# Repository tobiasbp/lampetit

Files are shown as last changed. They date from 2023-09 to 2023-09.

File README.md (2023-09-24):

# Lampetit Conversion
A project to convert the Lampetit lamp by Louis Poulsen to a portable LED lamp.

# Create the Gerber files

The following is the high level view of the process. Read the
[description from JLCPVB](https://jlcpcb.com/help/article/16-How-to-generate-Gerber-and-Drill-files-in-KiCad-6)
for all the details.

1. File -> Fabrication outputs -> Gerbers
2. Press _Plot_ to greate Gerbers
3. Press _Generate Drill Files..._

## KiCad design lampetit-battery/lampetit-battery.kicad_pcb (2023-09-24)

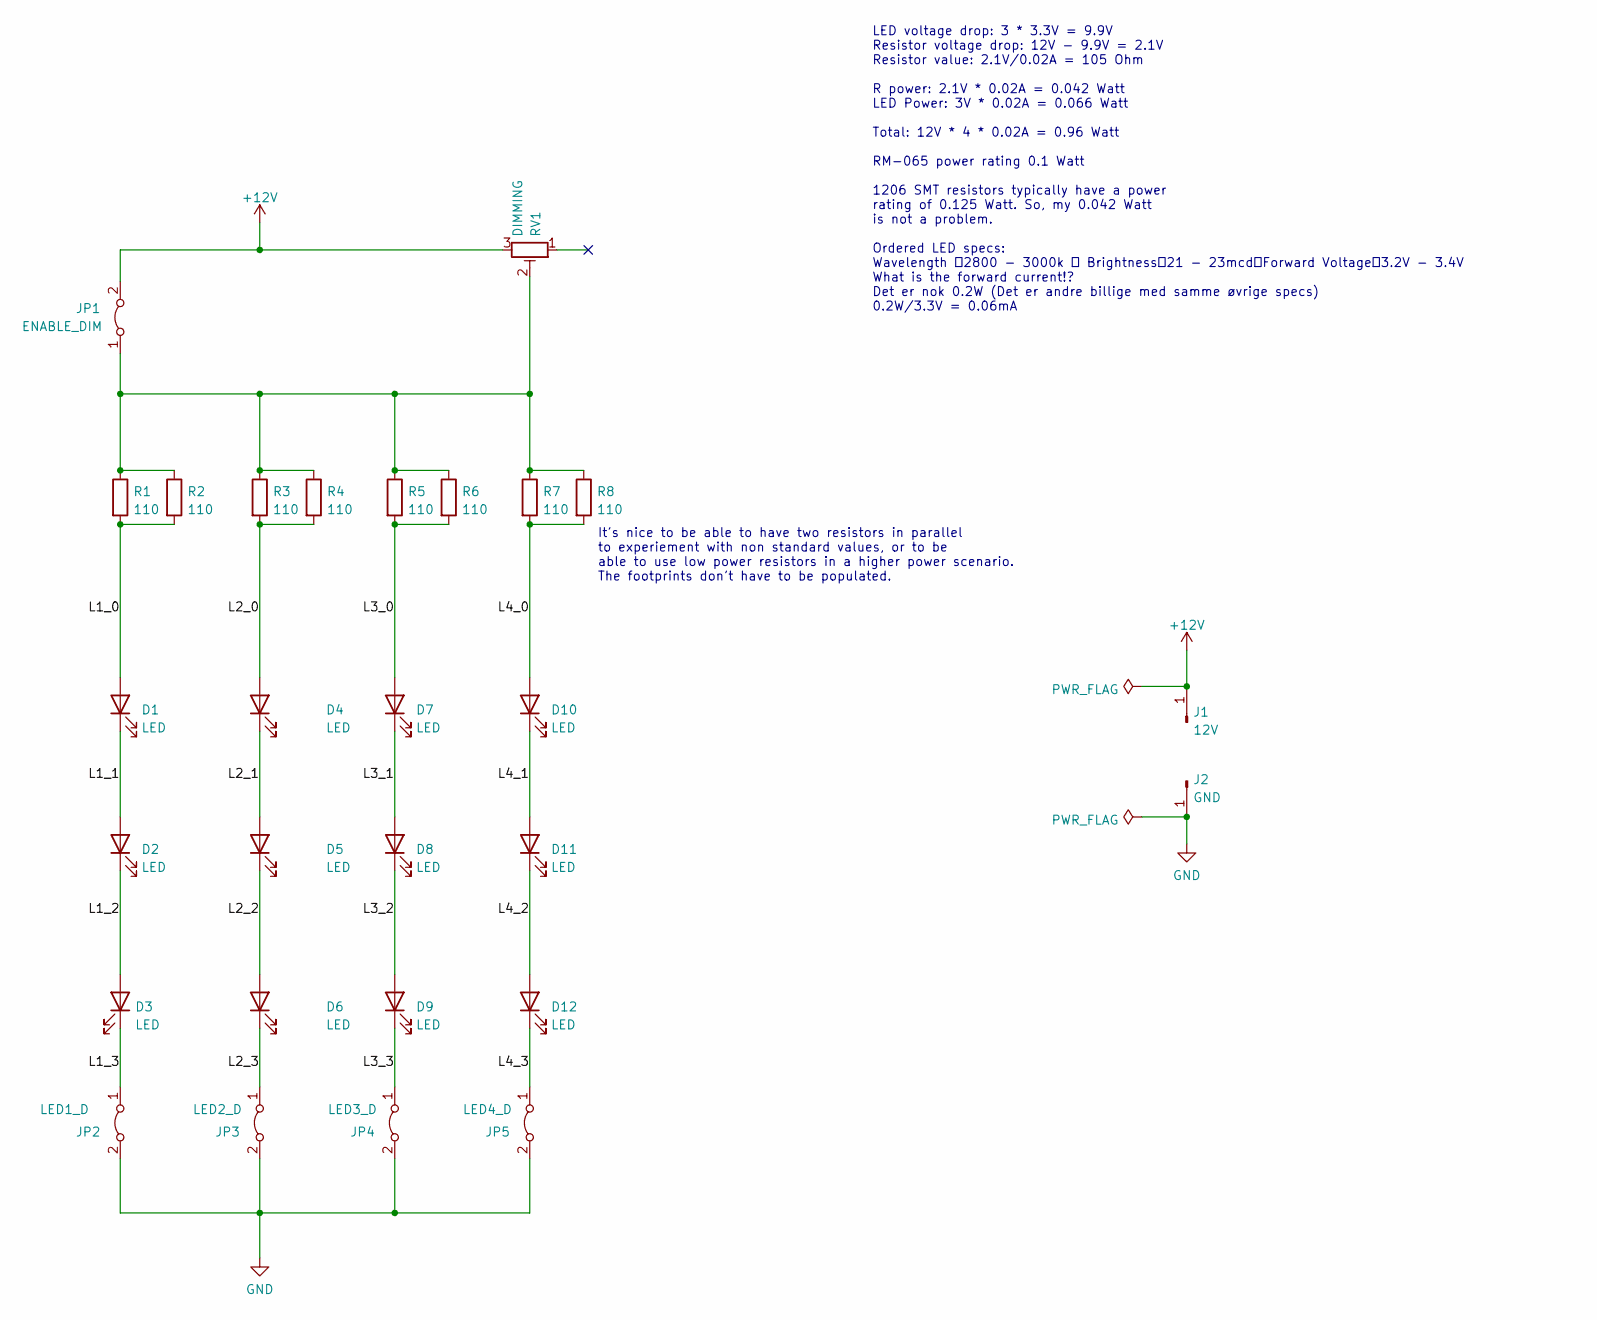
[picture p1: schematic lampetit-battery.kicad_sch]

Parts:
D1, D2, D3, D4, D5, D6, D7, D8, D9, D10, D11, D12: LED; LED_PLCC_2835_Handsoldering
J1: 12V; PinHeader_1x01_P2.54mm_Vertical
J2: GND; PinHeader_1x01_P2.54mm_Vertical
JP1: ENABLE_DIM; SolderJumper-2_P1.3mm_Bridged_Pad1.0x1.5mm
JP2: LED1_D; SolderJumper-2_P1.3mm_Bridged_Pad1.0x1.5mm
JP3: LED2_D; SolderJumper-2_P1.3mm_Bridged_Pad1.0x1.5mm
JP4: LED3_D; SolderJumper-2_P1.3mm_Bridged_Pad1.0x1.5mm
JP5: LED4_D; SolderJumper-2_P1.3mm_Bridged_Pad1.0x1.5mm
R1, R2, R3, R4, R5, R6, R7, R8: 110; R_1206_3216Metric_Pad1.30x1.75mm_HandSolder
RV1: DIMMING; Potentiometer_Runtron_RM-065_Vertical

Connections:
+12V: J1.1, JP1.2 (B), RV1.3
/L1_0: D1.2 (A), R1.2, R2.2
/L1_1: D1.1 (K), D2.2 (A)
/L1_2: D2.1 (K), D3.2 (A)
/L1_3: D3.1 (K), JP2.1 (A)
/L2_0: D4.2 (A), R3.2, R4.2
/L2_1: D4.1 (K), D5.2 (A)
/L2_2: D5.1 (K), D6.2 (A)
/L2_3: D6.1 (K), JP3.1 (A)
/L3_0: D7.2 (A), R5.2, R6.2
/L3_1: D7.1 (K), D8.2 (A)
/L3_2: D8.1 (K), D9.2 (A)
/L3_3: D9.1 (K), JP4.1 (A)
/L4_0: D10.2 (A), R7.2, R8.2
/L4_1: D10.1 (K), D11.2 (A)
/L4_2: D11.1 (K), D12.2 (A)
/L4_3: D12.1 (K), JP5.1 (A)
GND: J2.1, JP2.2 (B), JP3.2 (B), JP4.2 (B), JP5.2 (B)
unnamed: JP1.1 (A), R1.1, R2.1, R3.1, R4.1, R5.1, R6.1, R7.1, R8.1, RV1.2

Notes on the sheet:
LED voltage drop: 3 * 3.3V = 9.9V Resistor voltage drop: 12V - 9.9V = 2.1V Resistor value: 2.1V/0.02A = 105 Ohm R power: 2.1V * 0.02A = 0.042 Watt LED Power: 3V * 0.02A = 0.066 Watt Total: 12V * 4 * 0.02A = 0.96 Watt RM-065 power rating 0.1 Watt 1206 SMT resistors typically have a power rating of 0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
It's nice to be able to have two resistors in parallel to experiement with non standard values, or to be able to use low power resistors in a higher power scenario. The footprints don't have to be populated.

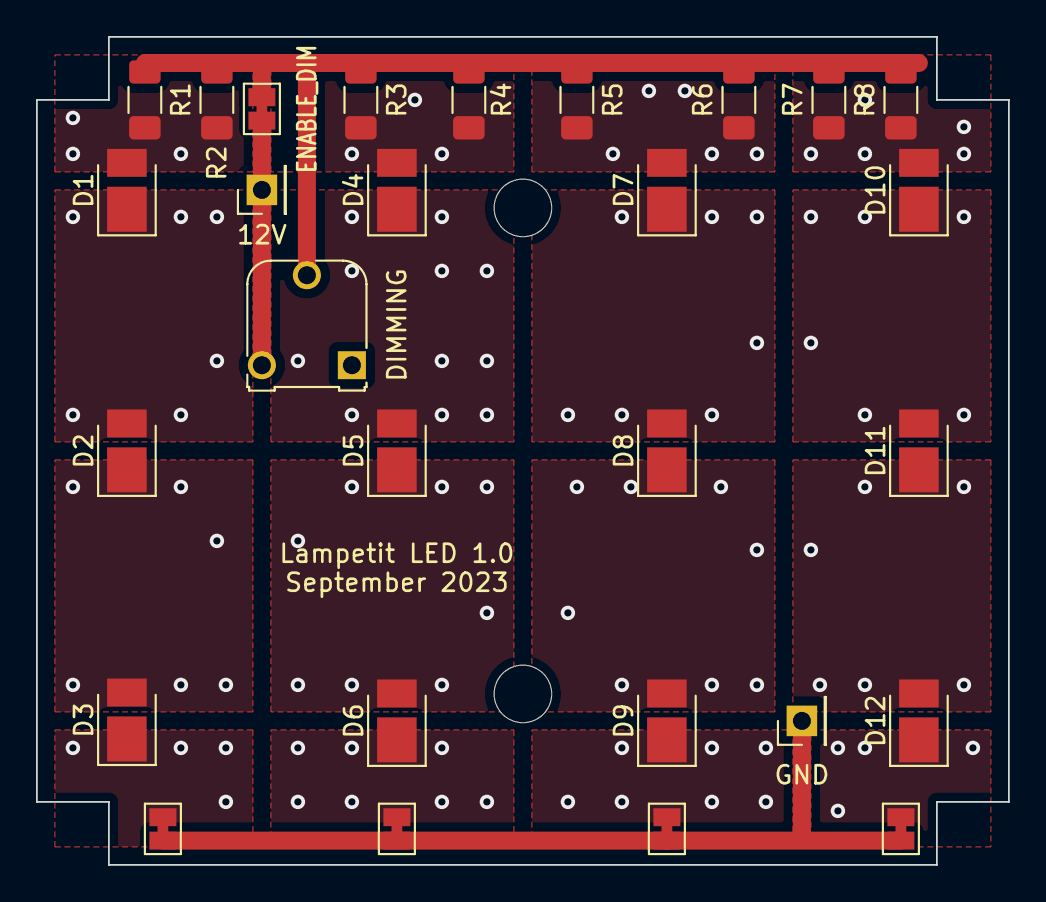
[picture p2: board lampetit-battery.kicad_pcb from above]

Board: 2 copper layers, 54.0 x 46.0 mm, 28 parts (0 on the bottom side), 19 nets.

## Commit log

2023-09-24 Add KiCad project
    [lampetit-battery.kicad_pcb, lampetit-battery.kicad_sch]
2023-09-24 Add gerbers for version v1.0 of the board
    [lampetit-battery-B_Cu.gbl, lampetit-battery-B_Mask.gbs, lampetit-battery-B_Paste.gbp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]
